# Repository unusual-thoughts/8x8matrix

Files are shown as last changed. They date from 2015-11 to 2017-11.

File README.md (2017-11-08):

Backpack for 8x8 RGB LED matrix
==============================

This is a simple breakout board for 8x8 RGB matrices like the [GTM2088ARGB](http://www.ebay.com/itm/5mm-8x8-Matrix-RGB-LED-Common-Anode-Full-Colour-60-60mm-/370699782315)  
It uses a [TLC5947](http://www.ti.com/product/tlc5947) that provides 24 12 bit current sink PWM channels, and a 74HC138 3 to 8 line decoder followed by P-channel MOSFETs to drive the rows.  

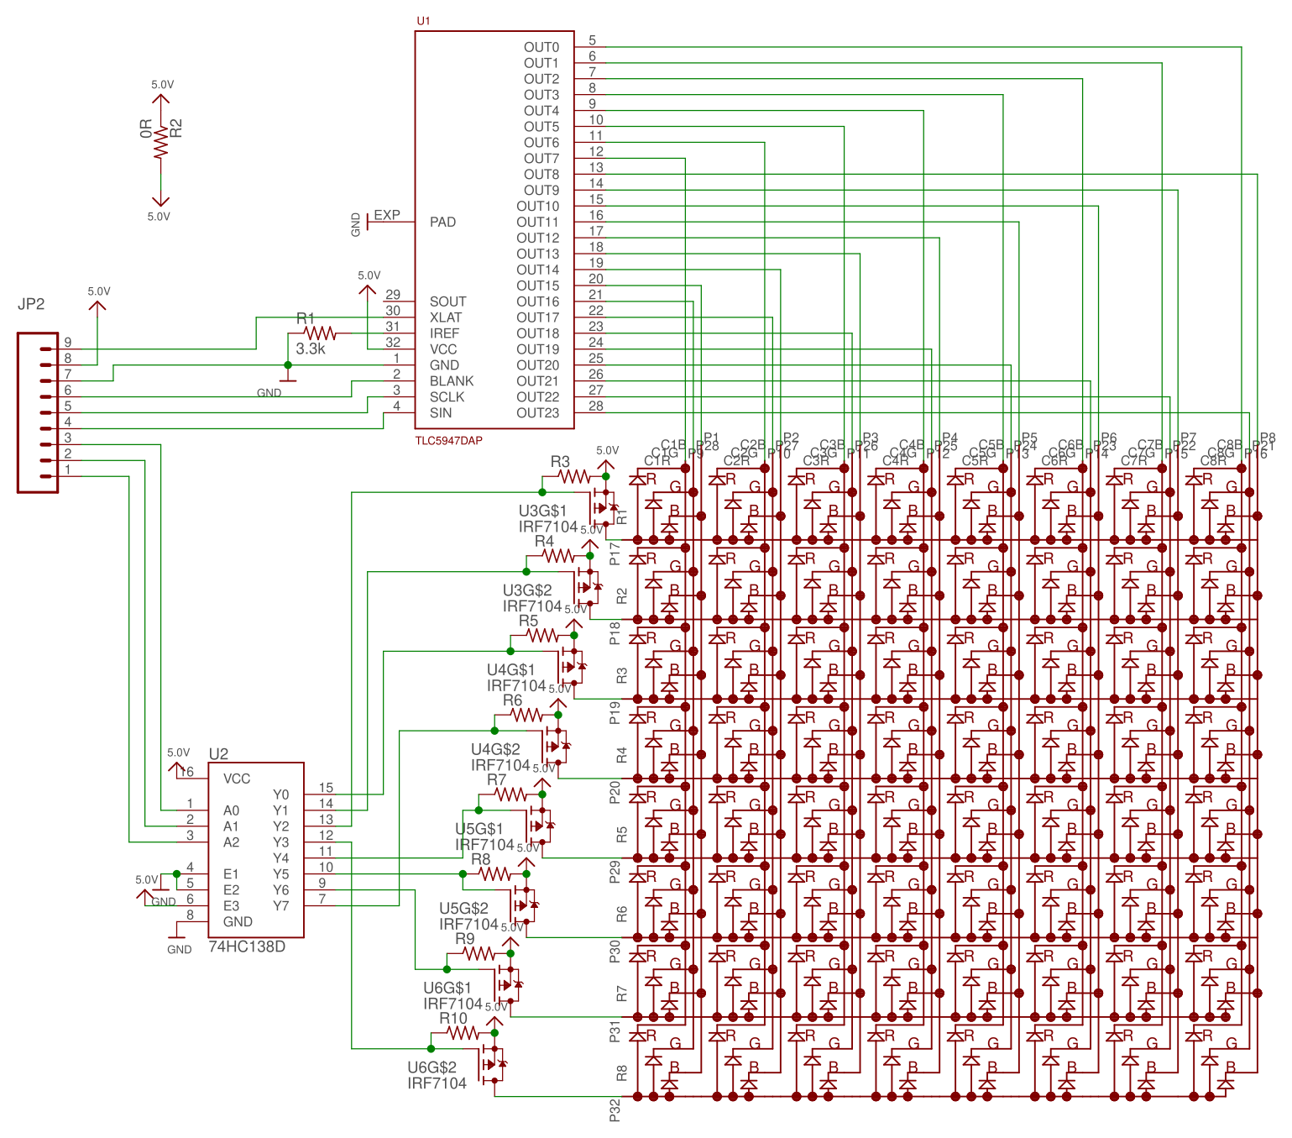
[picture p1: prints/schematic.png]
schematic


The needed Eagle libraries are in `eagle-lbr/`  
The whole thing fits on a single layer PCB.  
The matrix is controlled through the 9-pin header with this pinout:

Pin number	| Label	| Description
----------	| -----	| -----------
1			| A2	| row higher bit
2			| A1	| row middle bit
3			| A0	| row lower bit
4			| SIN	| TLC data (24x12 bit = 36 bytes)
5			| SCLK	| TLC clock
6			| BLANK	| TLC blank columns and reset PWM timer
7			| GND	| Ground
8			| VCC	| +5V
9			| XLAT	| TLC latch data

To get everything to fit on a single sided board, I had to make weird column and row assignments:

A0	| A1	| A2	| Row Number
--- | ---	| ---	| ----------
0	| 0		| 0		| 2
0	| 0		| 1		| 1
0	| 1		| 0		| 0
0	| 1		| 1		| 7
1	| 0		| 0		| 4
1	| 0		| 1		| 5
1	| 1		| 0		| 6
1	| 1		| 1		| 3

TLC channel	| Columns
----------  | ------
0-7			| Red 0-7
8-15		| Blue 0-7
16-23		| Green 7-0 (inverted order)

The `arduino-lbr/` directory contatins a modified version of the Tlc5940 library by Alex Leone, named Tlc5947. Like its counterpart, it can use arduino hardware spi to speed things up to an acceptable refresh rate. The basic bitbang code flickers quite a bit, even with direct port manipulation.

The `arduino/` directory contains a demo arduino sketch using that library.

layers

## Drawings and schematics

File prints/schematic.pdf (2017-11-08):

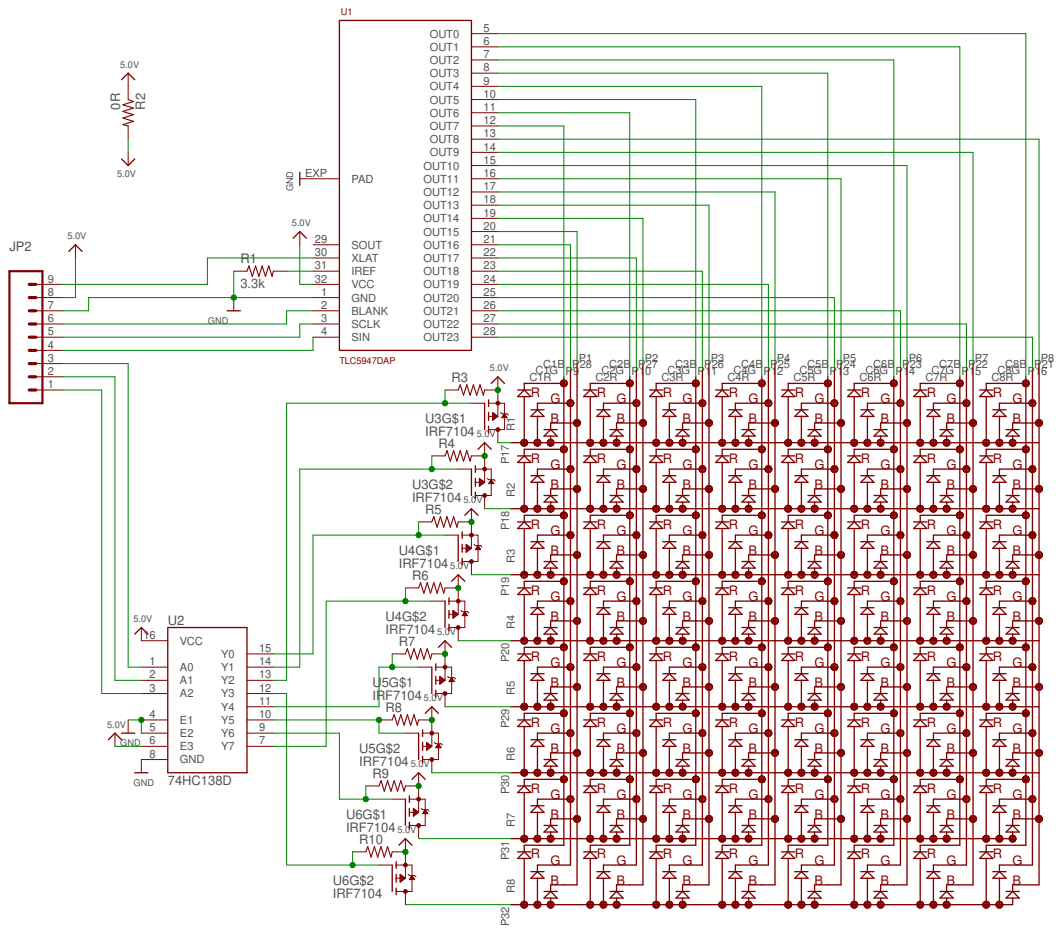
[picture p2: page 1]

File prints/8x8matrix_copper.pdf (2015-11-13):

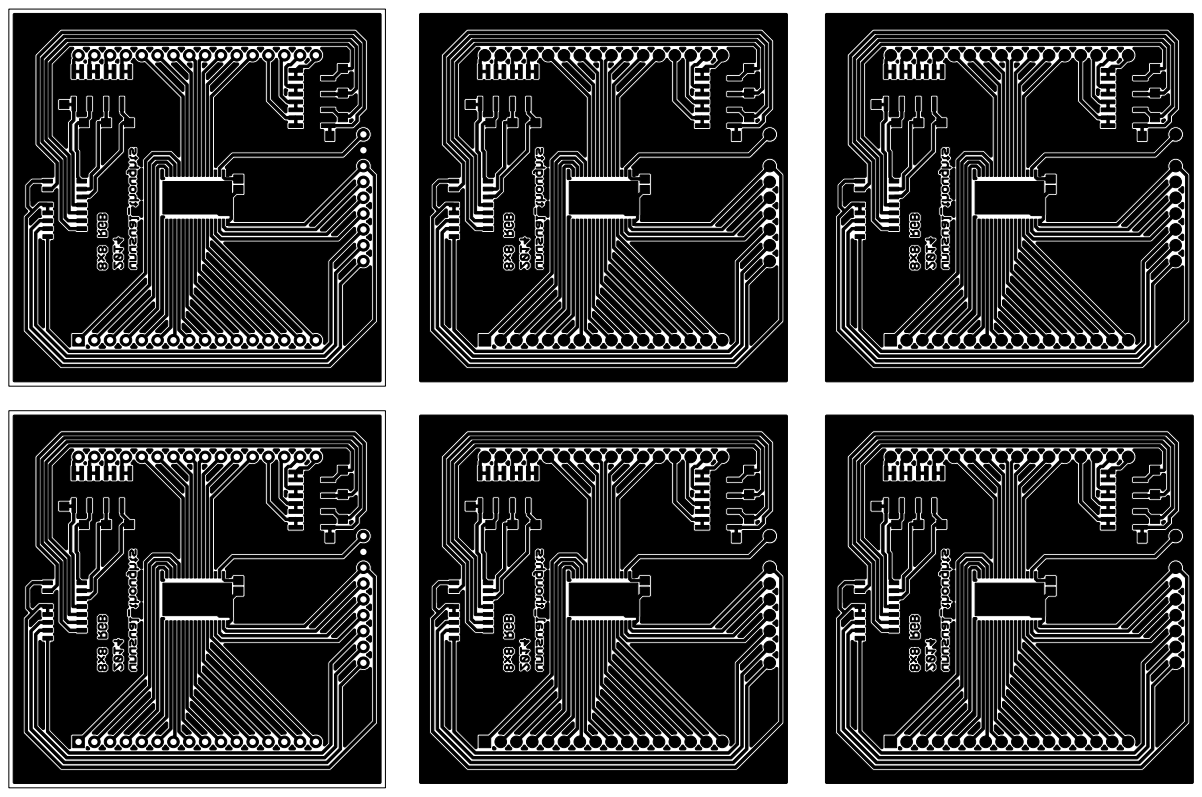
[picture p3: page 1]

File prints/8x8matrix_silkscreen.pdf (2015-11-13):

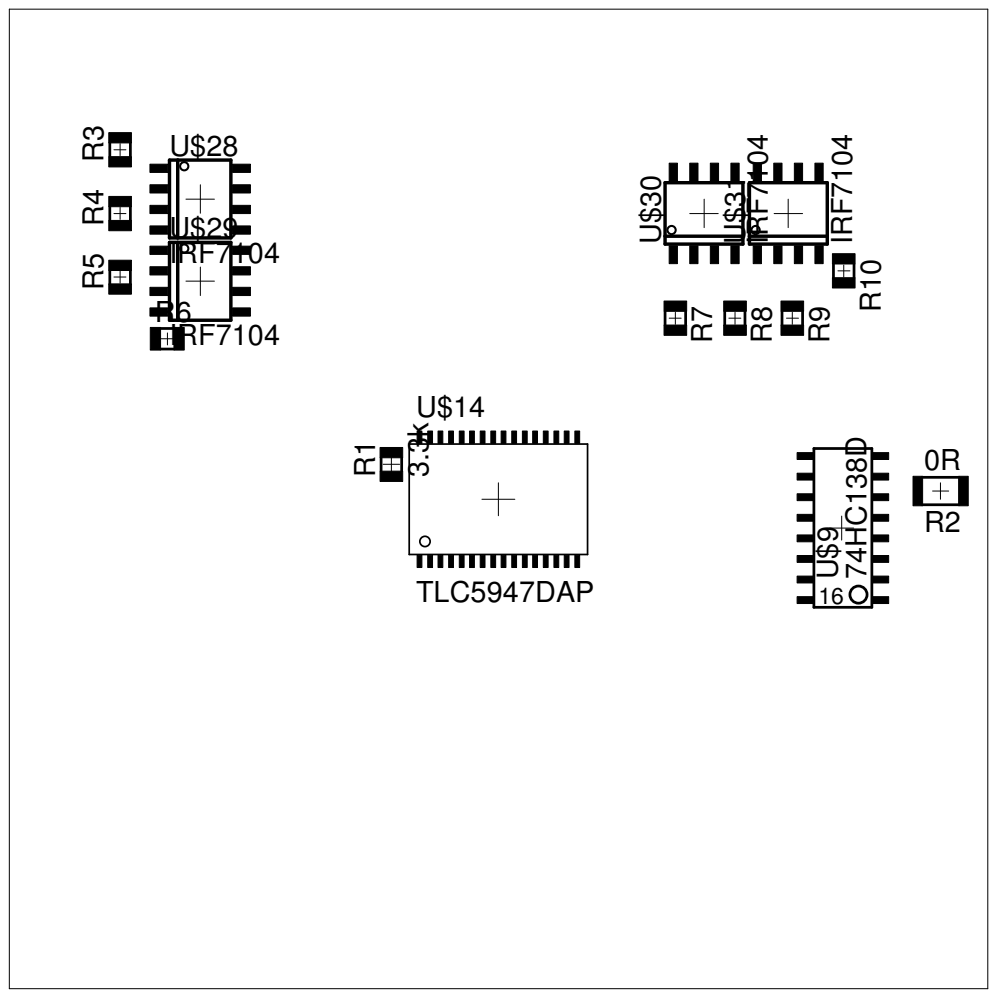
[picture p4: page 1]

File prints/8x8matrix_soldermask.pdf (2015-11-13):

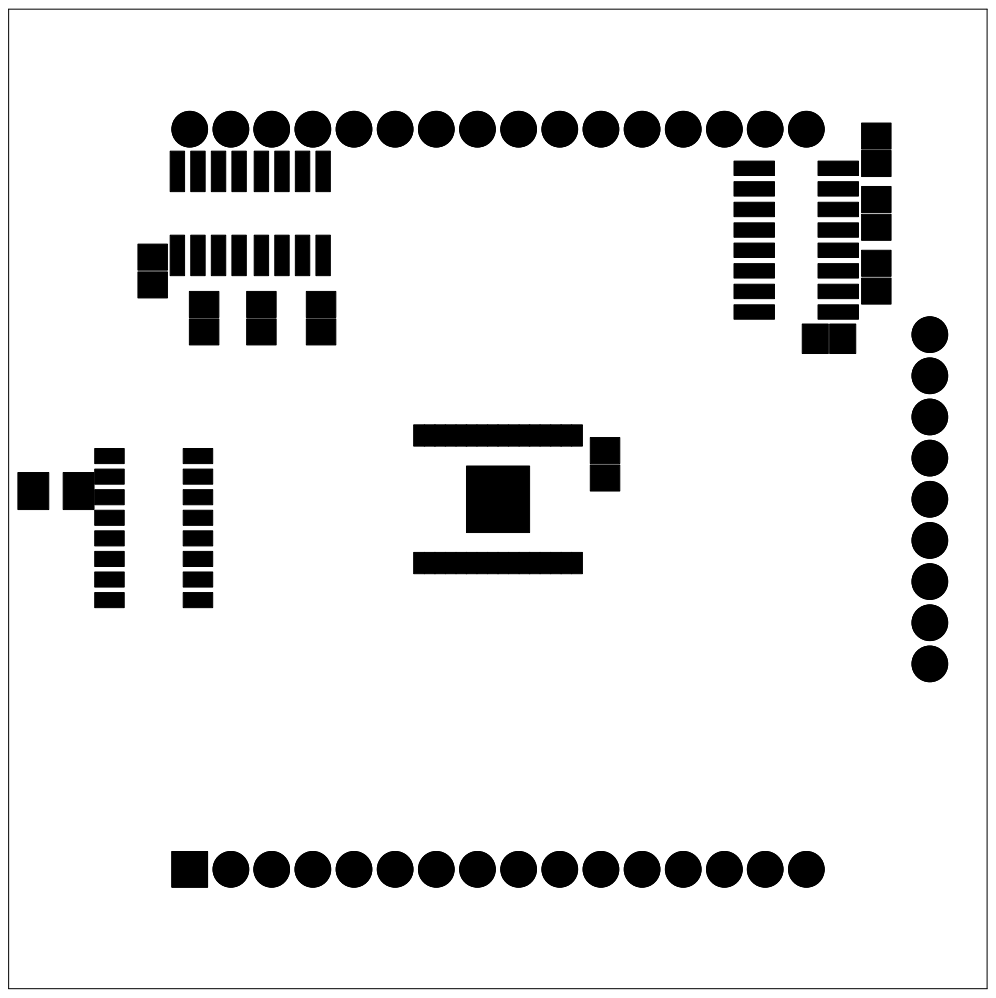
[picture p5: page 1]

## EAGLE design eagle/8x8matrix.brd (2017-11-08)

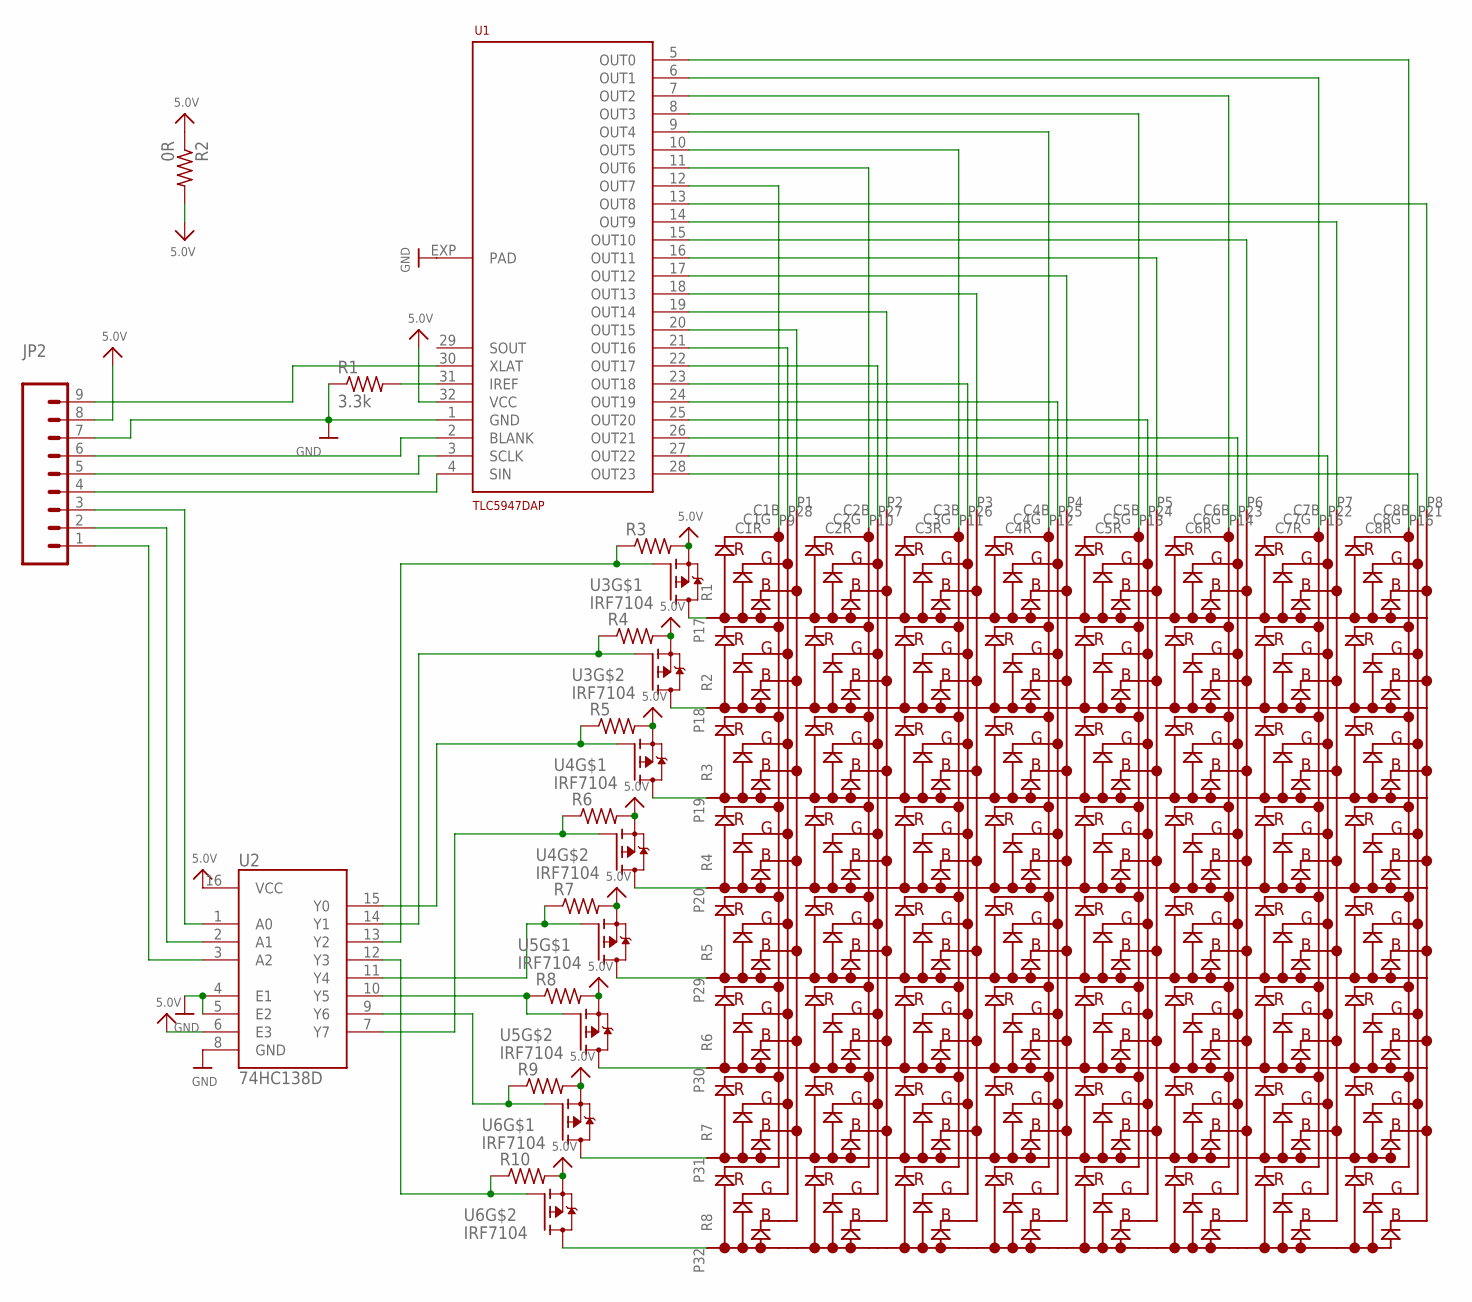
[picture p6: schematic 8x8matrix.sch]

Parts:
JP2: M09; 1X09
R1: 3.3k; R0805
R2: 0R; M1206
R3, R4, R5, R6, R7, R8, R9, R10: R-US_R0805; R0805
U1: TLC5947DAP; HTSSOP32DAP
U2: 74HC138D; SO-16
U3, U4, U5, U6: IRF7104; SOIC8
U$1: GTM2088ARGB; 8X8MATRIX

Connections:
5.0V: JP2.8, R2.1, R2.2, R3.2, R4.2, R5.2, R6.2, R7.2, R8.2, R9.2, R10.2, U1.32 (VCC), U2.6 (E3), U2.16 (VCC), U3.1 (S), U3.3 (S), U4.1 (S), U4.3 (S), U5.1 (S), U5.3 (S), U6.1 (S), U6.3 (S)
A0: JP2.3, U2.1 (A0)
A1: JP2.2, U2.2 (A1)
A2: JP2.1, U2.3 (A2)
BLANK: JP2.6, U1.2 (BLANK)
GND: JP2.7, R1.1, U1.1 (GND), U1.EXP (PAD), U2.4 (E1), U2.5 (E2), U2.8 (GND)
unnamed: U1.5 (OUT0), U$1.P16 (C8R)
unnamed: U1.6 (OUT1), U$1.P15 (C7R)
unnamed: U1.7 (OUT2), U$1.P14 (C6R)
unnamed: U1.8 (OUT3), U$1.P13 (C5R)
unnamed: U1.9 (OUT4), U$1.P12 (C4R)
unnamed: U1.10 (OUT5), U$1.P11 (C3R)
unnamed: U1.11 (OUT6), U$1.P10 (C2R)
unnamed: U1.12 (OUT7), U$1.P9 (C1R)
unnamed: U1.13 (OUT8), U$1.P8 (C8B)
unnamed: U1.14 (OUT9), U$1.P7 (C7B)
unnamed: U1.15 (OUT10), U$1.P6 (C6B)
unnamed: U1.16 (OUT11), U$1.P5 (C5B)
unnamed: U1.17 (OUT12), U$1.P4 (C4B)
unnamed: U1.18 (OUT13), U$1.P3 (C3B)
unnamed: U1.19 (OUT14), U$1.P2 (C2B)
unnamed: U1.20 (OUT15), U$1.P1 (C1B)
unnamed: U1.21 (OUT16), U$1.P28 (C1G)
unnamed: U1.22 (OUT17), U$1.P27 (C2G)
unnamed: U1.23 (OUT18), U$1.P26 (C3G)
unnamed: U1.24 (OUT19), U$1.P25 (C4G)
unnamed: U1.25 (OUT20), U$1.P24 (C5G)
unnamed: U1.26 (OUT21), U$1.P23 (C6G)
unnamed: U1.27 (OUT22), U$1.P22 (C7G)
unnamed: U1.28 (OUT23), U$1.P21 (C8G)
unnamed: R1.2, U1.31 (IREF)
unnamed: U4.7 (D), U4.8 (D), U$1.P19 (R3)
unnamed: U3.5 (D), U3.6 (D), U$1.P18 (R2)
unnamed: U3.7 (D), U3.8 (D), U$1.P17 (R1)
unnamed: U5.7 (D), U5.8 (D), U$1.P29 (R5)
unnamed: U6.7 (D), U6.8 (D), U$1.P31 (R7)
unnamed: U4.5 (D), U4.6 (D), U$1.P20 (R4)
unnamed: U5.5 (D), U5.6 (D), U$1.P30 (R6)
unnamed: U6.5 (D), U6.6 (D), U$1.P32 (R8)
SCLK: JP2.5, U1.3 (SCLK)
SIN: JP2.4, U1.4 (SIN)
XLAT: JP2.9, U1.30 (XLAT)
Y0: R5.1, U2.15 (Y0), U4.2 (G)
Y1: R4.1, U2.14 (Y1), U3.4 (G)
Y2: R3.1, U2.13 (Y2), U3.2 (G)
Y3: R10.1, U2.12 (Y3), U6.4 (G)
Y4: R7.1, U2.11 (Y4), U5.2 (G)
Y5: R8.1, U2.10 (Y5), U5.4 (G)
Y6: R9.1, U2.9 (Y6), U6.2 (G)
Y7: R6.1, U2.7 (Y7), U4.4 (G)

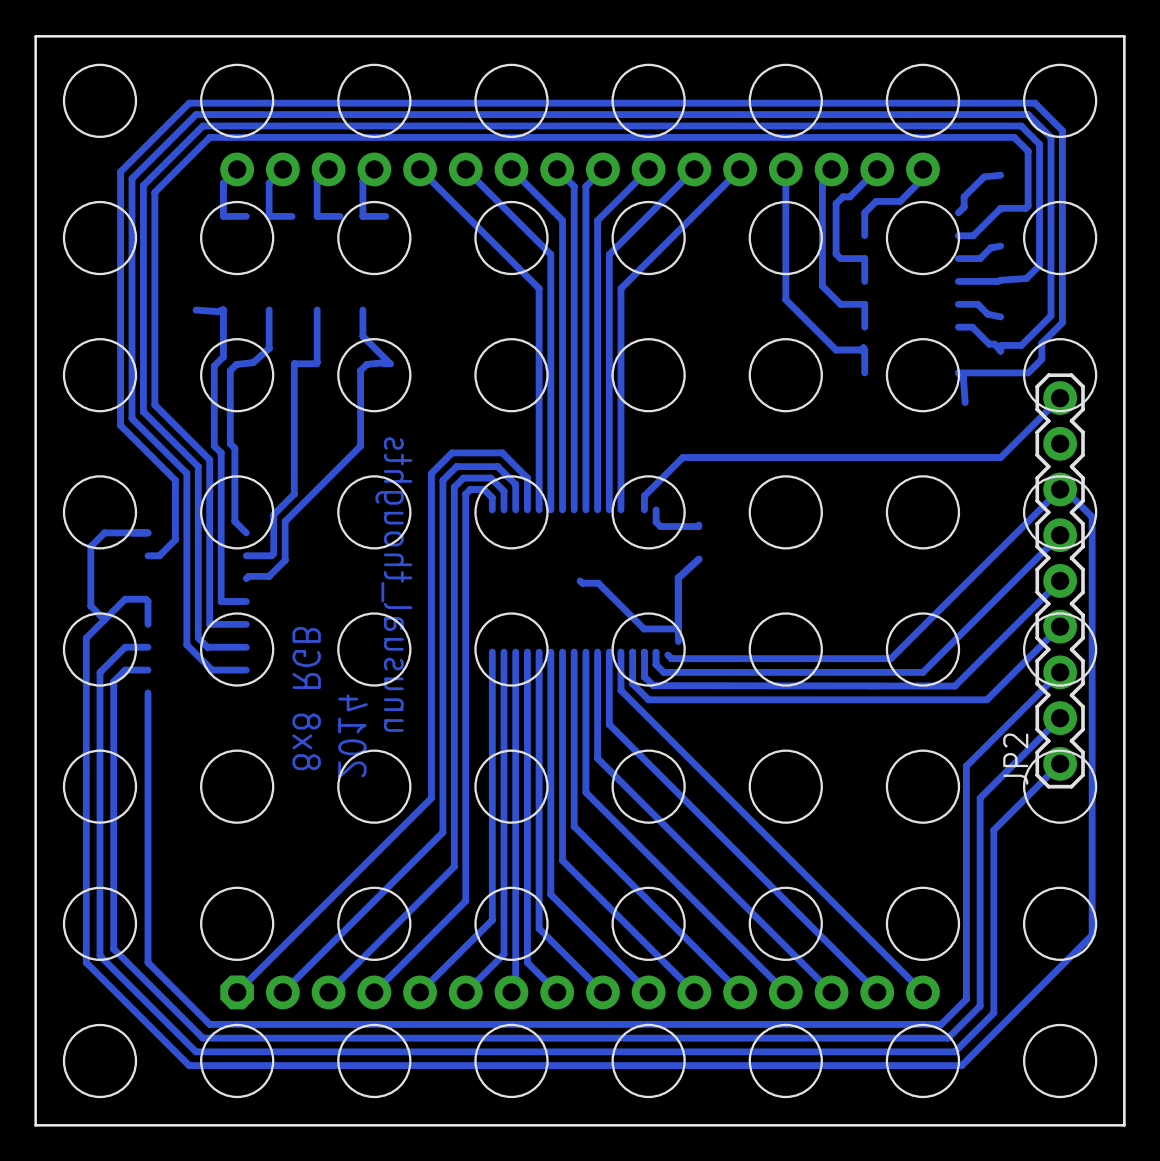
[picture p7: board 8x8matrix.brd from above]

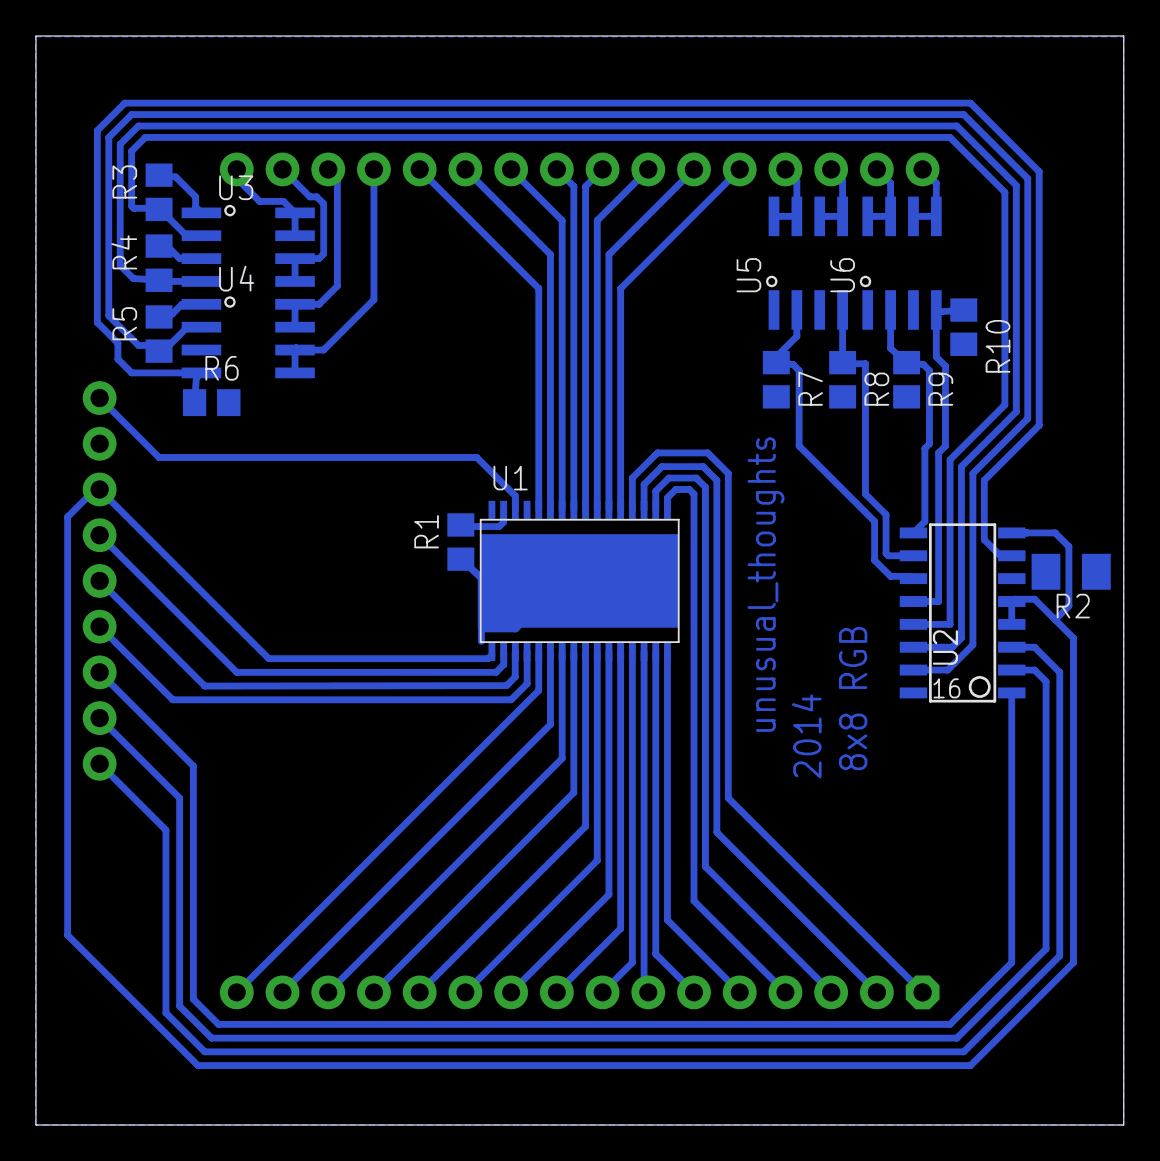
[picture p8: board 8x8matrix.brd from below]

Board: 2 copper layers, 60.4 x 60.5 mm, 18 parts (16 on the bottom side), 50 nets.

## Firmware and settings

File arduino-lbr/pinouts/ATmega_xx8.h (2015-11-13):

/*  Copyright (c) 2009 by Alex Leone <acleone ~AT~ gmail.com>

    This file is part of the Arduino TLC5940 Library.

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
    You should have received a copy of the GNU General Public License
    along with The Arduino TLC5940 Library.  If not, see
    <http://www.gnu.org/licenses/>. */

#ifndef TLC_ATMEGA_XX8_H
#define TLC_ATMEGA_XX8_H

/** \file
    SPI and timer pins for the ATmega168/48/88.  Don't edit these.  All
    changeable pins are defined in tlc_config.h */


/** SIN (Arduino digital pin 7) -> SIN (TLC pin 26) */
#define DEFAULT_BB_SIN_PIN      PD7
#define DEFAULT_BB_SIN_PORT     PORTD
#define DEFAULT_BB_SIN_DDR      DDRD
/** SCLK (Arduino digital pin 4) -> SCLK (TLC pin 25) */
#define DEFAULT_BB_SCLK_PIN     PD4
#define DEFAULT_BB_SCLK_PORT    PORTD
#define DEFAULT_BB_SCLK_DDR     DDRD

/** MOSI (Arduino digital pin 11) -> SIN (TLC pin 26) */
#define TLC_MOSI_PIN     PB3
#define TLC_MOSI_PORT    PORTB
#define TLC_MOSI_DDR     DDRB

/** SCK (Arduino digital pin 13) -> SCLK (TLC pin 25) */
#define TLC_SCK_PIN      PB5
#define TLC_SCK_PORT     PORTB
#define TLC_SCK_DDR      DDRB

/** SS will be set to output as to not interfere with SPI master operation.
    If you have changed the pin-outs and the library doesn't seem to work
    or works intermittently, make sure this pin is set correctly.  This pin
    will not be used by the library other than setting its direction to
    output. */
#define TLC_SS_PIN       PB2
#define TLC_SS_DDR       DDRB

/** OC1A (Arduino digital pin 9) -> XLAT (TLC pin 24) */
#define XLAT_PIN     PB1
#define XLAT_PORT    PORTB
#define XLAT_DDR     DDRB

/** OC1B (Arduino digital pin 10) -> BLANK (TLC pin 23) */
#define BLANK_PIN    PB2
#define BLANK_PORT   PORTB
#define BLANK_DDR    DDRB

/** OC2B (Arduino digital pin 3) -> GSCLK (TLC pin 18) */
#define GSCLK_PIN    PD3
#define GSCLK_PORT   PORTD
#define GSCLK_DDR    DDRD

#endif

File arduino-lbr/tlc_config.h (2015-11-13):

/*  Copyright (c) 2009 by Alex Leone <acleone ~AT~ gmail.com>

    This file is part of the Arduino TLC5940 Library.

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
    You should have received a copy of the GNU General Public License
    along with The Arduino TLC5940 Library.  If not, see
    <http://www.gnu.org/licenses/>. */

#ifndef TLC_CONFIG_H
#define TLC_CONFIG_H

#include <stdint.h>

/** \file
    Configuration for the Arduino Tlc5940 library.  After making changes to
    this file, delete Tlc5940.o in this folder so the changes are applied.

    A summary of all the options:
    - Number of TLCs daisy-chained: NUM_TLCS (default 1)
    - Enable/Disable VPRG functionality: VPRG_ENABLED (default 0)
    - Enable/Disable XERR functionality: XERR_ENABLED (default 0)
    - Should the library use bit-banging (any pins) or hardware SPI (faster):
        DATA_TRANSFER_MODE (default TLC_SPI)
    - Which pins to use for bit-banging: SIN_PIN, SIN_PORT, SIN_DDR and
        SCLK_PIN, SCLK_PORT, SCLK_DDR
    - The PWM period: TLC_PWM_PERIOD (be sure to change TLC_GSCLK_PERIOD
        accordingly!)

    How to change the pin mapping:
    - Arduino digital pin 0-7  = PORTD, PD0-7
    - Arduino digital pin 8-13 = PORTB, PB0-5
    - Arduino analog pin  0-5  = PORTC, PC0-5 */

/** Bit-bang using any two i/o pins */
#define TLC_BITBANG             1
/** Use the much faster hardware SPI module */
#define TLC_SPI                 2

/* ------------------------ START EDITING HERE ----------------------------- */

/** Number of TLCs daisy-chained.  To daisy-chain, attach the SOUT (TLC pin 17)
    of the first TLC to the SIN (TLC pin 26) of the next.  The rest of the pins
    are attached normally.
    \note Each TLC needs it's own IREF resistor */
#define NUM_TLCS                1

/* If you use a LED matrix, set the number of rows here. Otherwise set it to 1*/
#define NUM_ROWS                8

/** Determines how data should be transfered to the TLCs.  Bit-banging can use
    any two i/o pins, but the hardware SPI is faster.
    - Bit-Bang = TLC_BITBANG
    - Hardware SPI = TLC_SPI (default) */
#define DATA_TRANSFER_MODE      TLC_SPI
//#define DATA_TRANSFER_MODE    TLC_BITBANG 


/* This include is down here because the files it includes needs the data
   transfer mode */
#include "pinouts/chip_includes.h"

/* Set DATA_TRANSFER_MODE to TLC_BITBANG and change the pins below if you need
   to use different pins for sin and sclk.  The defaults are defined in
   pinouts/ATmega_xx8.h for most Arduino's. */

#if DATA_TRANSFER_MODE == TLC_BITBANG
/** SIN (TLC pin 26) */
# define SIN_PIN                 DEFAULT_BB_SIN_PIN
# define SIN_PORT                DEFAULT_BB_SIN_PORT
# define SIN_DDR                 DEFAULT_BB_SIN_DDR
/** SCLK (TLC pin 25) */
# define SCLK_PIN                DEFAULT_BB_SCLK_PIN
# define SCLK_PORT               DEFAULT_BB_SCLK_PORT
# define SCLK_DDR                DEFAULT_BB_SCLK_DDR
#endif

#if NUM_ROWS != 1
# include "pinouts/matrix_includes.h"
# define A0_PIN                  DEFAULT_A0_PIN
# define A0_PORT                 DEFAULT_A0_PORT
# define A0_DDR                  DEFAULT_A0_DDR

# define A1_PIN                  DEFAULT_A1_PIN
# define A1_PORT                 DEFAULT_A1_PORT
# define A1_DDR                  DEFAULT_A1_DDR

# define A2_PIN                  DEFAULT_A2_PIN
# define A2_PORT                 DEFAULT_A2_PORT
# define A2_DDR                  DEFAULT_A2_DDR
#endif

/** If more than 16 TLCs are daisy-chained, the channel type has to be uint16_t.
    Default is uint8_t, which supports up to 16 TLCs. */
#define TLC_CHANNEL_TYPE        uint8_t



/* ------------------------- STOP EDITING HERE ----------------------------- */

#if DATA_TRANSFER_MODE == TLC_SPI
/** SIN (TLC pin 26) */
#define SIN_PIN                 TLC_MOSI_PIN
#define SIN_PORT                TLC_MOSI_PORT
#define SIN_DDR                 TLC_MOSI_DDR
/** SCLK (TLC pin 25) */
#define SCLK_PIN                TLC_SCK_PIN
#define SCLK_PORT               TLC_SCK_PORT
#define SCLK_DDR                TLC_SCK_DDR
#endif

#if NUM_ROWS != 1
//# define ROW_MASK (~(1 << A0_PIN) | (1 << A1_PIN) | (1 << A2_PIN))
# define ROW_MASK (0xFF && ~(1 << A0_PIN) && ~(1 << A1_PIN) && ~(1 << A2_PIN))
//# define ROW_MASK 31
#endif

#if !(DATA_TRANSFER_MODE == TLC_BITBANG \
 || DATA_TRANSFER_MODE == TLC_SPI)
#error "Invalid DATA_TRANSFER_MODE specified, see DATA_TRANSFER_MODE"
#endif

/* Various Macros */

/** Arranges 2 grayscale values (0 - 4095) in the packed array format (3 bytes).
    This is for array initializers only: the output is three comma seperated
    8-bit values. */
#define GS_DUO(a, b)    ((a) >> 4), ((a) << 4) | ((b) >> 8), (b)


#if VPRG_ENABLED
/** Arranges 4 dot correction values (0 - 63) in the packed array format.
    \see setDCtoProgmemArray */
#define DC_QUARTET(a, b, c, d)   ((a) << 2) | ((b) >> 4), \
                                 ((b) << 4) | ((c) >> 2), \
                                 ((c) << 6) | (d)
#endif

#endif

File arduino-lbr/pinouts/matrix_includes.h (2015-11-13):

#ifndef TLC_MATRIX_INCLUDES_H
# define TLC_MATRIX_INCLUDES_H

/** A0 (Arduino digital pin 5) -> row lower bit */
#define DEFAULT_A0_PIN      PD5
#define DEFAULT_A0_PORT     PORTD
#define DEFAULT_A0_DDR      DDRD
/** A1 (Arduino digital pin 6) -> row middle bit  */
#define DEFAULT_A1_PIN     PD6
#define DEFAULT_A1_PORT    PORTD
#define DEFAULT_A1_DDR     DDRD
/** A1 (Arduino digital pin 7) -> row middle bit  */
#define DEFAULT_A2_PIN     PD7
#define DEFAULT_A2_PORT    PORTD
#define DEFAULT_A2_DDR     DDRD


#endif

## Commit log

2017-11-08 update eagle schematic
    [8x8matrix.brd, 8x8matrix.sch]
2017-11-08 add schematic images
2017-11-08 add schematic to readme

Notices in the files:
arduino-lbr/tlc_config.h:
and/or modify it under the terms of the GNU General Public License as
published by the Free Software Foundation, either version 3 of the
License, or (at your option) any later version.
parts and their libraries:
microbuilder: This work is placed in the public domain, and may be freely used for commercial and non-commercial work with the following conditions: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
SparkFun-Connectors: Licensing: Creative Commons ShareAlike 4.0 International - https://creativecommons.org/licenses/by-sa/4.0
